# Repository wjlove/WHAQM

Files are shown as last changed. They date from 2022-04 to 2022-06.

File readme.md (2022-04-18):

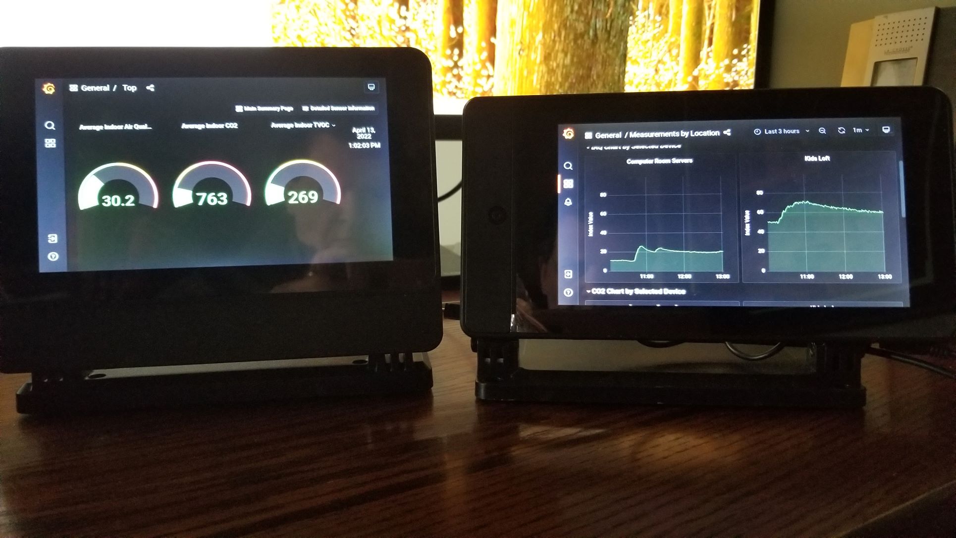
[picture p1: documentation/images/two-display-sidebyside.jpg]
The Whole Home Air Quality Monitoring Project
 

*An extension of the balenAIR project that allows for multiple sensor devices in various location within your home or any indoor location*

# Whole Home Air Quality Monitoring Project
**_Both this code and documentation are currently under construction)_**

## Reasoning

My office door is often closed and I was wondering if the quality of the air in my office was affecting my health. I wanted to measure/understand the levels of hazardous gasses and overall CO2 concentrations in my office during working hours as those are good indicators of the quality of the air in an enclosed space.   There are many products on the market that individuals can purchase that will monitor indoor air quality, however as a tinkerer I wanted to explore building one myself.  After some online research into DIY and open source projects I came across the excellent baleaAIR (https://github.com/balena-io-playground/balena-iaq) endeavor and thought this might be interesting to build.  I started collecting the necessary components and proceeded constructing one following the guidelines provided inline.  

During the process of testing my initial build device I noticed that the measurements reported were wildly different throughout the day and often those measurement readings were in the described danger or warning zones.  I thought I’d done everything correctly, and indeed the values were changing over time, so what was possible explanation?  As one of several tests, I moved my device to another room in my home and noted markedly different results, these measurements were stable and “safe” and changed very slowly over time.  With those results in hand, I visited several other rooms in my home and noticed each one produced results that were generally slightly different by location and fluctuated only mildly during the day.  

 It is from here I wondered if having a sensor device in each room, monitored by a central location might be useful and thus this project was born. (And of course, I also stopped closing my office door!)

## New Features

At its core, this project is simply an extension of the great work done on the balenAIR project and adds the following features:

- A balenAIR like device with a touchscreen display
- Ability to collect data from multiple balenaAIR and WHAQM devices
- Ability to display aggregated measurements from all devices
- Ability to use touchscren device to provide alerts - _currently broken due to prediction work, disabled_
- Ability to predict air quality conditions based on previous measurements - _not completed_

## Hardware Selection and Setup

The hardware items selected for use in this project are mostly defined by the balenAIR project and its original recommendations. There are a number of options when it comes to choosing these devices and cost, availability plus performance are some factors to consider when reviewing the parts below.

### Choosing your Pi

This project currently runs on a Raspberry Pi, so you'll need one of the following compatible devices:

- [Pi 3B](https://www.raspberrypi.com/products/raspberry-pi-3-model-b/)
- [Pi 3B+](https://www.raspberrypi.com/products/raspberry-pi-3-model-b-plus/)
- [Pi 4](https://www.raspberrypi.com/products/raspberry-pi-4-model-b/)

If you plan on having a significant number of sensor devices in multiple locations I would recommend that you consider using a Pi 4 as the main device. The air quality prediction software can be rather compute intensive over time and a Pi 4 also provides a "snappier" experience when using the touch screen.

### The Display and Case

There are several options for choosing a physical case that will house the Raspberry Pi, the touchscreen device and all the sensors. You can even consider making your own for a personal touch.  After some review and consideration I committed to the [SmartiPi Touch Pro - Small](https://smarticase.com/products/smartipi-touch-pro). It supports the original [Raspberry Pi Touch Display](https://www.raspberrypi.com/products/raspberry-pi-touch-display/) which I have selected as my prefered touchscreen device and has plenty of internal space to house all the necessary sensors.  Both are easily available for purchase, well supported and currently reasonably priced.  

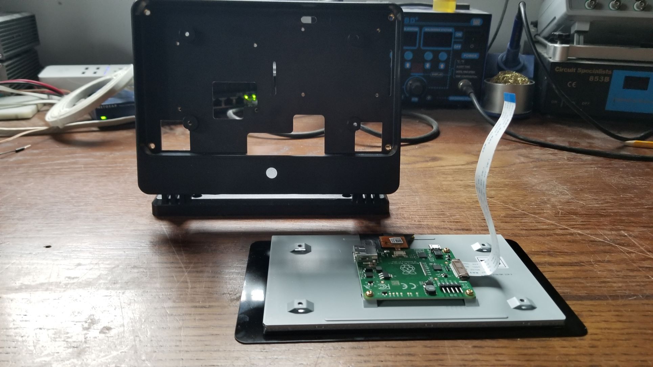
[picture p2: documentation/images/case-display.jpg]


### Sensors

The sensors used in this project evaluate the air surrounding the device and return data that is used to determine your air quality index or AQI. You can find more about how this number and how it is calculated at [AirNow](https://www.airnow.gov/aqi/aqi-basics/). Like balenAIR, WHAQM supports the three different sensors listed below. You can choose to have one, two, or all three present in your device, depending on your budget and air quality analysis needs.

| Sensor | Detects | Description |  Specifications (approx.) |
| --- | --- | --- | --- |
| [PMSA003I](https://www.adafruit.com/product/4632) | Smoke, dust, dirt, pollen particles | laser-scattering type  | 0.3-1.0,1.0-2.5, 2.5-10 Micrometer particles |
| [SCD-40](https://www.adafruit.com/product/5187) | Exhaled breath and burning fossil fuels |  CO2 photoacoustic sensor CO2 (plus temp and humidity)  | 400 - 2000 PPM |
| [SGP-30](https://www.adafruit.com/product/3709) | Gasses emitted by solid and liquid products  |  VOC (and eCO2) Hot-plate MOX sensor | eCO2 400-60,000 ppm, TVOC 0-60,000 ppb |

All of these sensors use the popular I2C protocol to communicate with the Pi and include [Qwiic](https://www.sparkfun.com/qwiic) connectors so you don't need to do any soldering to use these sensors.

### Sensor Carrier Board

Installing the sensors inside the SmartiPi case requires a seperate sensor carrier board.  Ideally and ultimately this will be a 3D printed part but considering the time involved in that process I simply fabricated one using a spare blank PCB.  You can read about that process [here](https://github.com/wjlove/WHAQM/blob/main/documentation/carrier-board.md) along with details about its dimensions and hole locations.
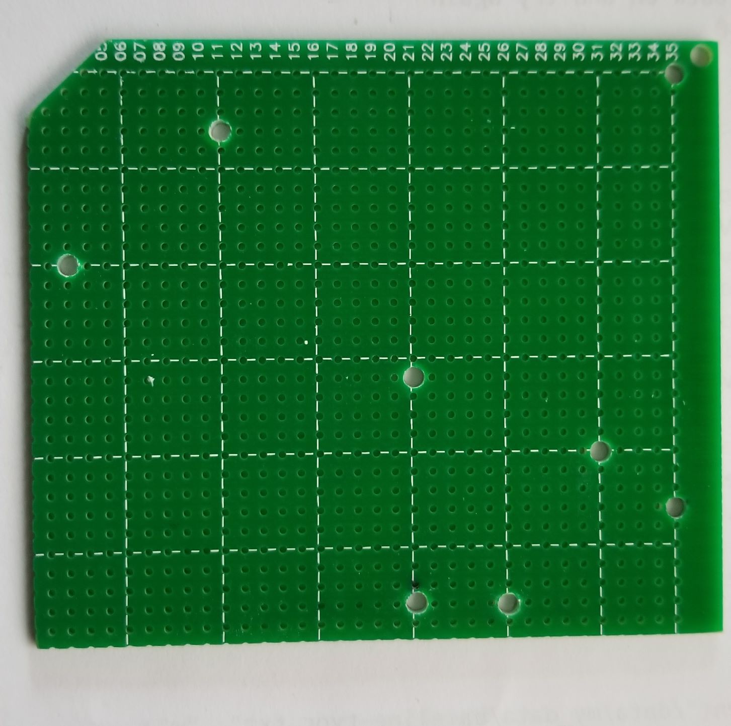
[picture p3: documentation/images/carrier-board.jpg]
 _Carrier board with holes_

As it currently stands this design is not ideal as a considerable amount of heat is generated internally by both the Raspberry Pi and the touchscreen display thus affecting the temperature measurements provided by the SCD-40 sensor unit by as much as 5 degrees.  Various insulating mitigations, as well as other air flow considerations, can be applied to the case and the sensor carrier board to reduce this effect. However my results to date have been varied and require further investigation.  The SmartiPi case does come with a fan which you can install and resolves this issue but the additional noise created by the fan was unacceptable to me.
### Miscellaneous Items

Additionally you will need some SparkFun qwiic cables to connect the sensors together [100mm QT to QT cable](https://www.adafruit.com/product/4210) and a qwiic to female header cable to connect the sensors to the Raspberry Pi you selected [Qwiic to female header cable](https://www.adafruit.com/product/4397).  Lastly you will need a way to affix the sensors to the carrier board, I used some M2 screws and bolts but you could also use plastic spacers or double sided tape but I wouldn’t recommend the latter.

### Putting it All Together

I will not go into significant detail about building the SmartiPi case and installing the Raspberry Pi touchscreen display as those details can be found on the [SmartiCase web site](https://smarticase.com/products/smartipi-touch-pro?variant=39297984790591).  Installing your Raspberry Pi of choice and the sensor carrier board on the rear of the case is done using the supplied screws.  You may want to attach the power adapter before installing the carrier board as it is significantly harder to do so with that installed. 

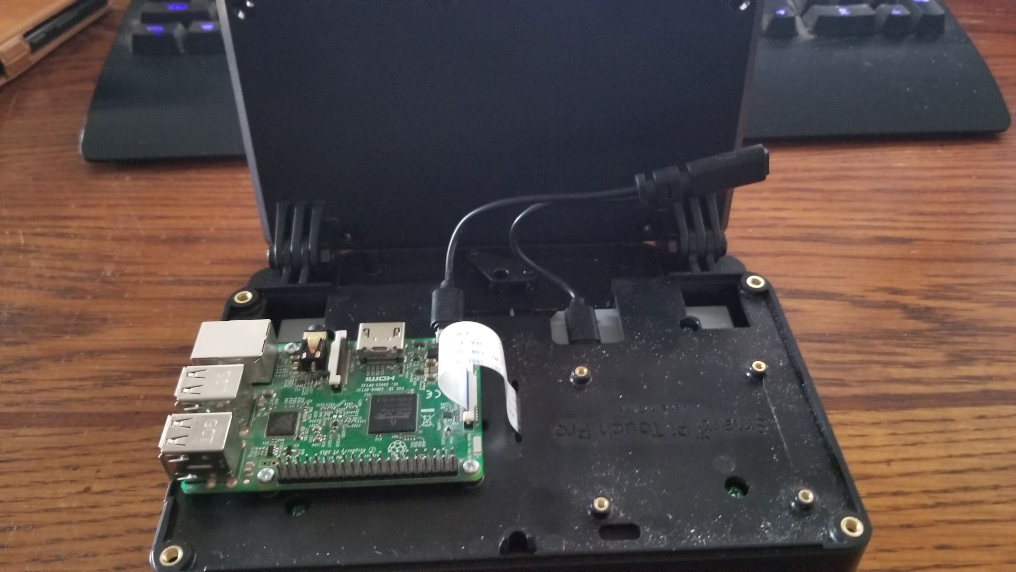
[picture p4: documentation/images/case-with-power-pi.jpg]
 *Install power connector first...*
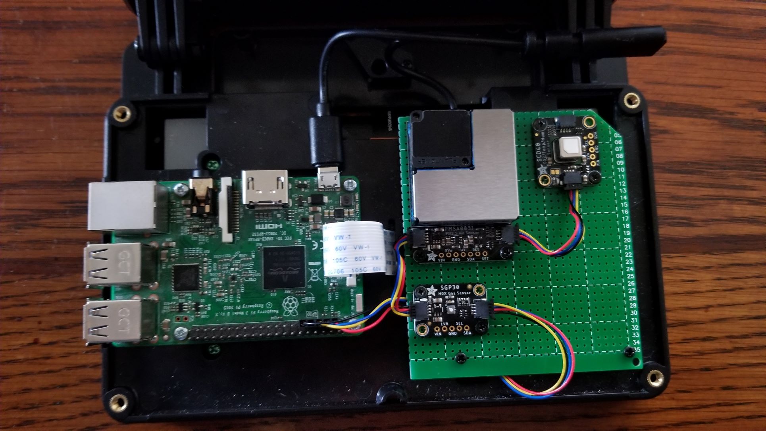
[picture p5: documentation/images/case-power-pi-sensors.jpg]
 *...then the sensors.*

Don’t put the back cover on just yet, we have to install the software and that requires access to the Raspberry Pi in the back.  

## Software Setup

This project assumes a fairly advanced level of knowledge about BalenaCloud and the steps to necessary to create a new fleet and new devices. If this is your first time deploying a project and you want to learn more about balena Cloud, I recommend familiarizing yourself by following the steps in this [Getting Started](https://www.balena.io/docs/learn/getting-started/raspberrypi4-64/nodejs/) tutorial.   While working with the tutorial keep in mind the Raspberry Pi device type you choose to use while building your WHAQM display as you will need to select the appropriate one while creating your fleet. After you have created a fleet with devices in your balenaCloud dashboard you can `balena push` this code to it the traditional way.

**_Or…._**

You can deploy this project in one click using the button below:

balena deploy button (https://dashboard.balena-cloud.com/deploy?repoUrl=https://github.com/wjlove/WHAQM)

This will automaticlly allow you to create (or use an existing) fleet, install the appropriate software and prepare everything for your first device deployment.  Pressing the button will walk you thru the necessary steps to get started. After providing the needed information balena Cloud will collect and build the appropriate software for your devices.  This will take some time, but you can follow the progress in the “Releases” window on the right:

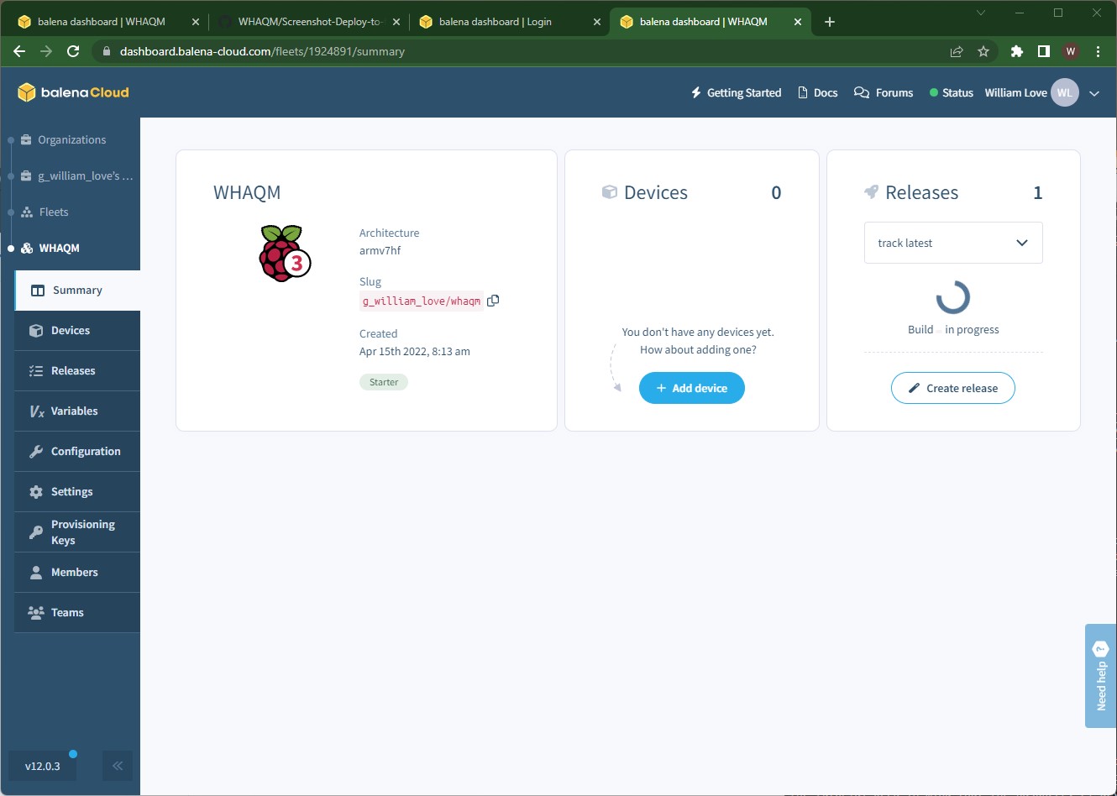
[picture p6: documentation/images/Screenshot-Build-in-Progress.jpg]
 _Build in progress_

When everything is complete you should see:

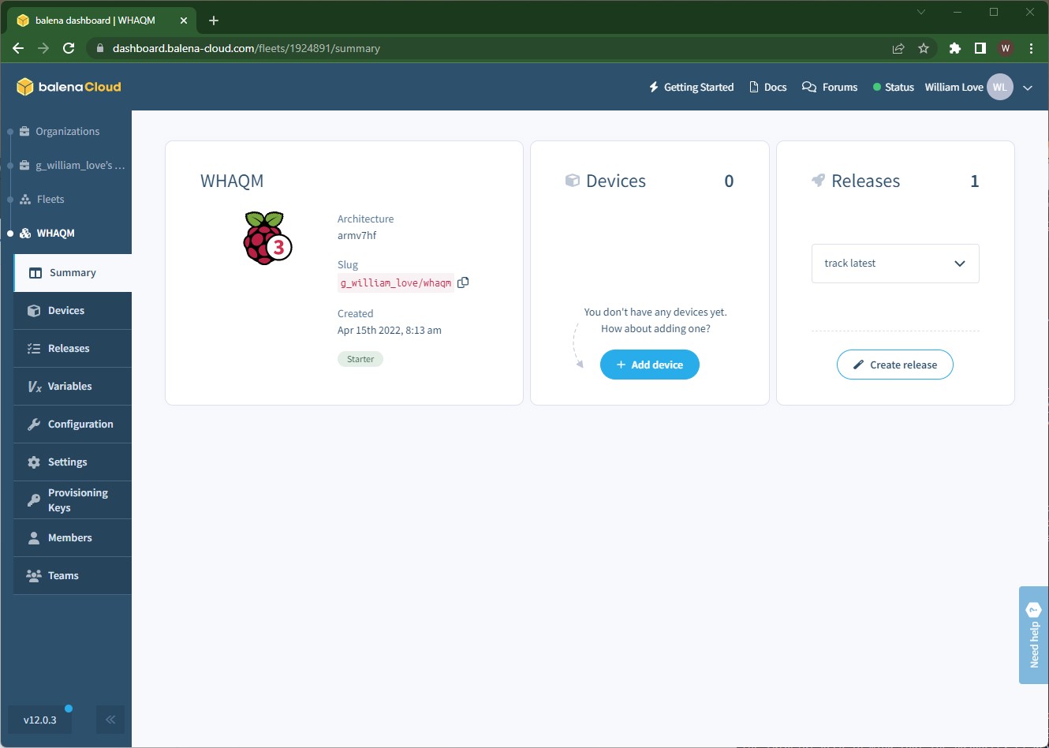
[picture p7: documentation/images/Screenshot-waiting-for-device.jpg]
 _Ready for your first device!_

Now you can add your first device by clicking on the “+ Add device” button.  While following the Instructions on the right be sure to remember the device type you used to build your display.  If you plan on using your device’s wireless networking ability be sure to select “Network Connection -> Wifi + Ethernet” and enter the appropriate network information.

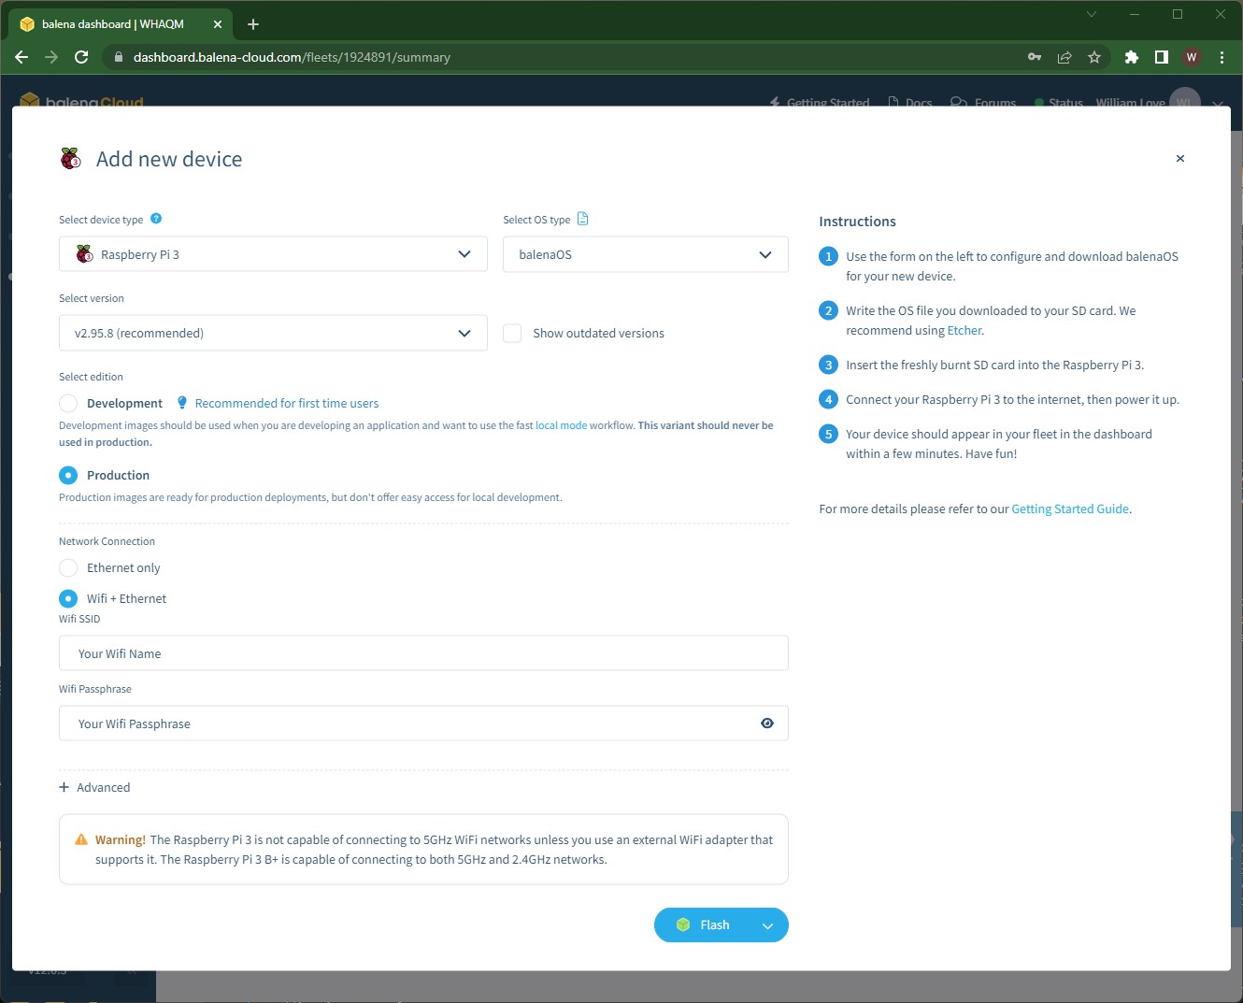
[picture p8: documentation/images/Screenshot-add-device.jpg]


((this section of my docuemnt needs work as the Instructions on the right are not completely clear on how to flash a device/SD card.  You need to either press the “Flash" button which automatically starts Etcher (if it is installed, if it is not installed then there are more steps), or select from the pull down nest to the "Flash" button to download the image file, ...and then flash it to the SD card with your software of choice.))

Once you have your freshly flashed SD card, install it in the Raspberry Pi:

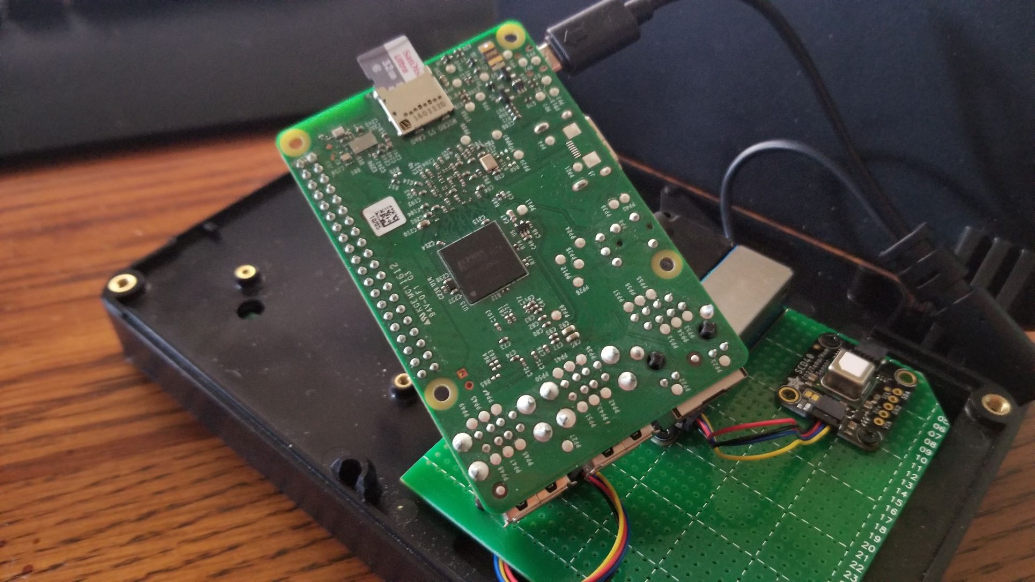
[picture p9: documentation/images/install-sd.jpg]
_SD card in back of the Raspberry Pi_

Power on the device and wait for it to boot up.  The first time the device powers up will take a significant amount of time as it needs to get an initial copy of the WHAQM software.  During this first step you should see the balena splash screen on your device:

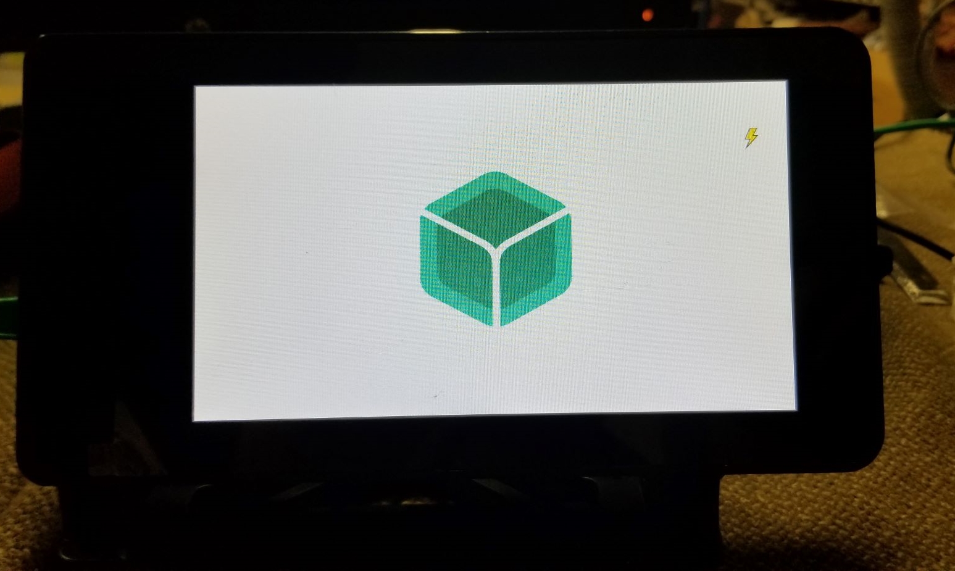
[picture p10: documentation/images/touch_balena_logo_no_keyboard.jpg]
 _Nice Logo…_

You can also verify that the software is being loaded on the device correctly by going to the balena Cloud dashboard and looking for a new device in the balena fleet you created.  In this example case, there is a device called “autumn-rock” and the “Status” is currently “Updating”:

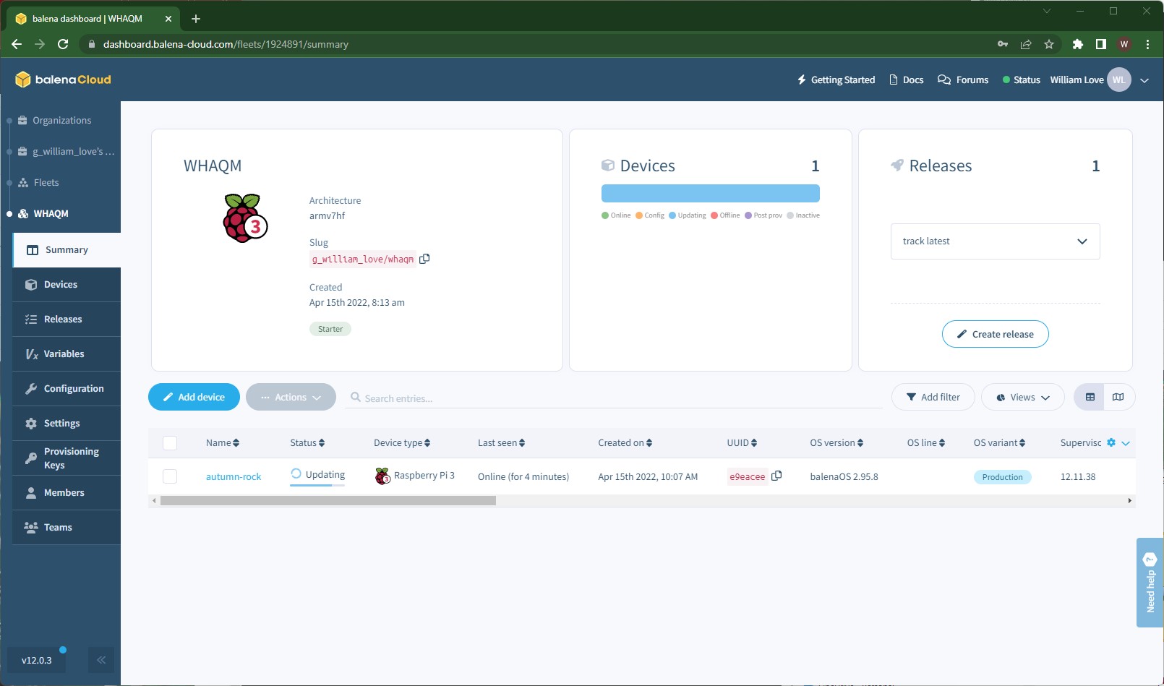
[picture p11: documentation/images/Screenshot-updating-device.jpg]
 

When the initial software has completed the loading process the “Status” will change to “Online” and you can click on the device name to get more detailed information about the device and the software that is running:

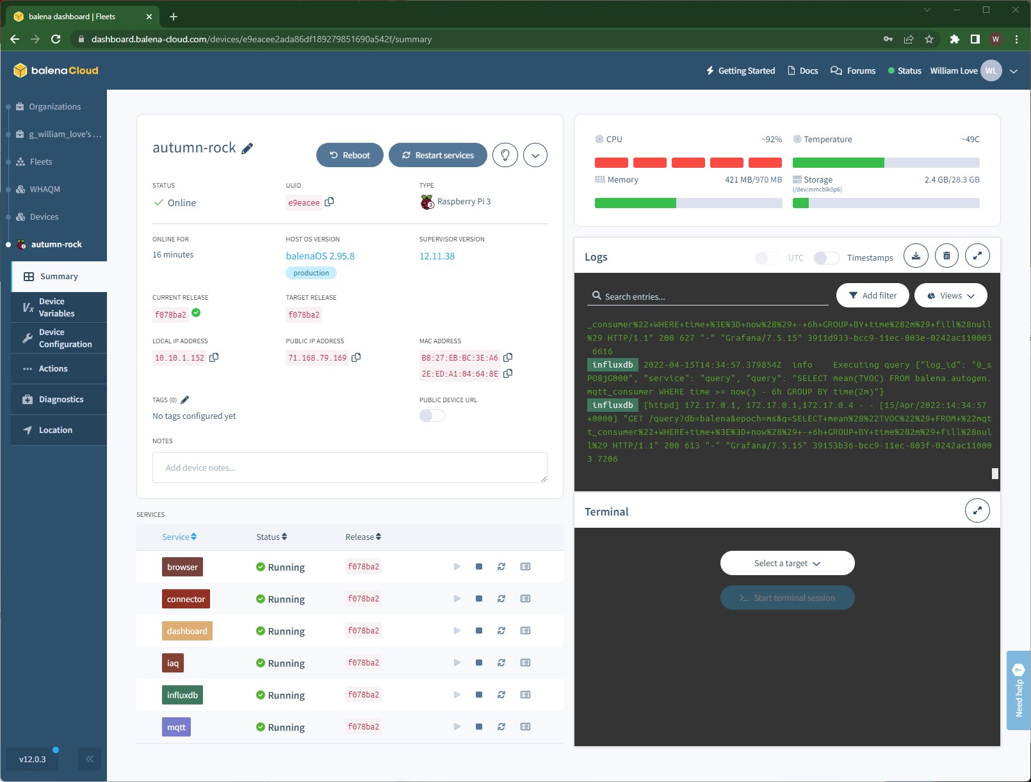
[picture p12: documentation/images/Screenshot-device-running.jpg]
_…you should see something like this…_

…and you should see the General/Top Screen on your WHAQM device:

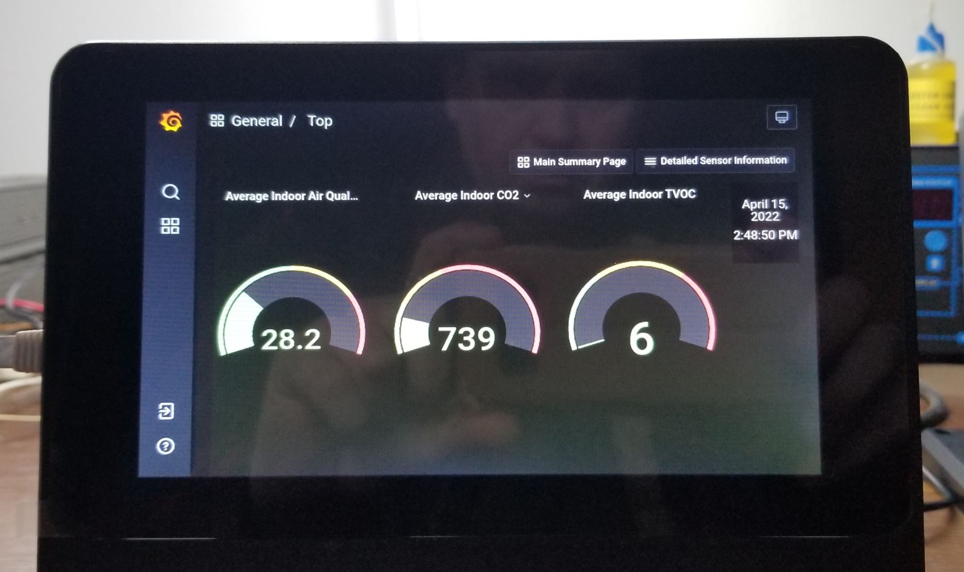
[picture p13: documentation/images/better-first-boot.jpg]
 _…nothing more to do here!_

### Using the WHAQM software

Design Goal Intro-  Using as many perdefined balena blocks as possible with as little modificationa as possible to build a new project.  Only real software modifications here are found in IAQ.py and Dashboard, all the hard work is handled by generic balena blocks.

***_outline_***

Intro-  

- brief overview of menus
  - top
    - main summary page
    - detailed sensor information
    - location measurement details
    - measurements by location

- review some of the buttons
    - time period
    - manual refresh
    - automatic refresh selection
    - view mode - add warning about touchscreen (can not disable yet)

- direct access via web browser
- making changes to Grafana dashboards

### Adding more devices....

***_outline_***

- currently supported devices
    - balenaAIR
    - WHAQM

- need WHAQM_SENSOR_NAME
- need modify mosquitto.conf file in MQTT container with WHAQM_COLLECTOR_URL
- for WHAQM devices, point browser block to WHAQM_COLLECTOR_URL

### Troubleshooting

- Software Tools
    - MQTT Explorer
    - InfluxBD Studio
    - Grafana Website

- HArdware Tools
    - ???

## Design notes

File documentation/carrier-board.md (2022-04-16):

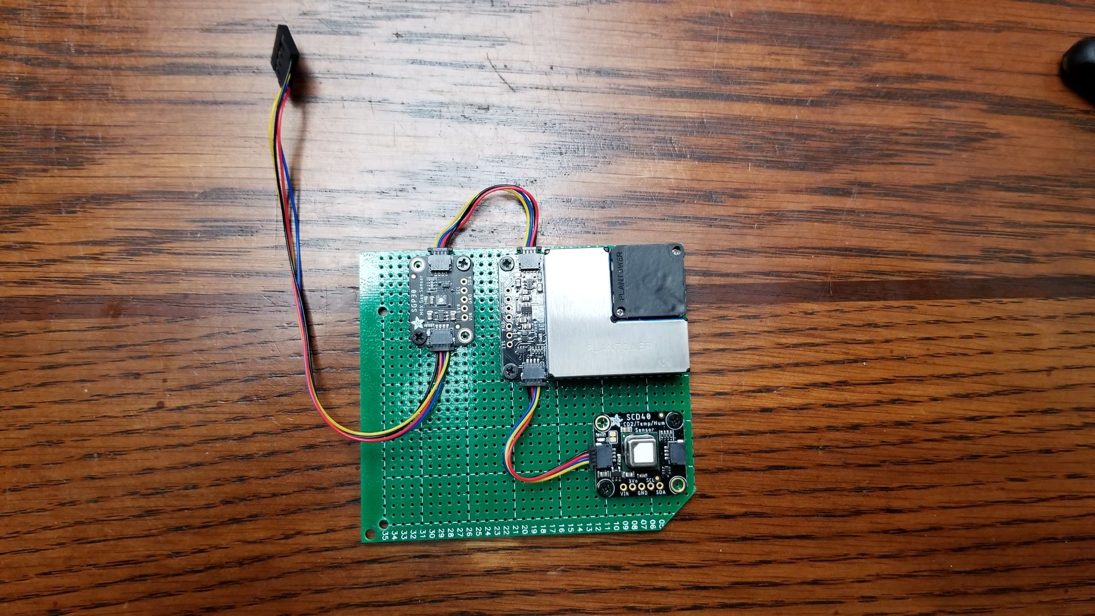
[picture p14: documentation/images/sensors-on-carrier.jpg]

_Solution to install sensors inside TouchScreen case for WHAQM project_

## WHAQM Sensor Carrier Board

Ultimately the sensor carrier board will be 3D printed but for now I just wanted to get something in place that would keep the build process moving along.  I happened to have some extra PCB prototyping boards in my parts supply so using them was a simple short term solution.  The process would include identifying a usable board and then drilling some holes to affix the sensors to the board with some M2 sized screws.  Using screws for my initial designs facilitated the ability to move various sensors as I explored placement options.  This would be very instrumental later as thermal issues became more problematic than expected. 

My initial selection of possible options produced these three boards:

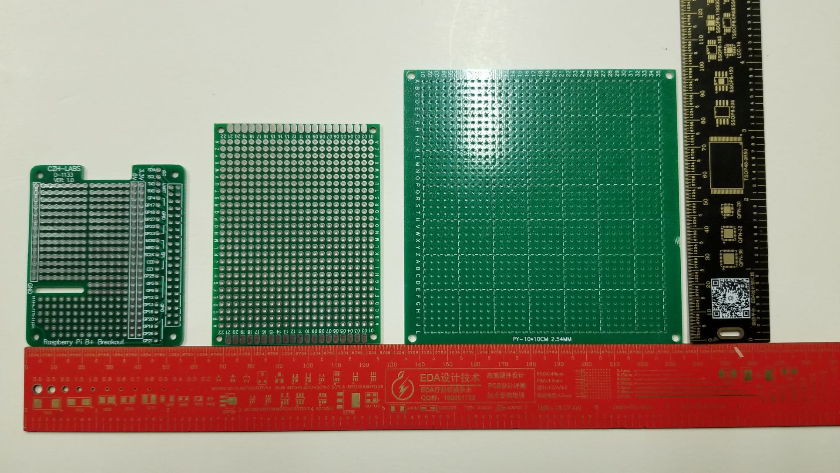
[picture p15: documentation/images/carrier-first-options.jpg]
_Some PCB options_

The first board on the left is an original Raspberry Pi Hat prototyping board and while it already has the case mounting holes pre-drilled it was too small to hold all three sensors. The middle board had enough space but needed holes drilled for mounting in the case.  The last board on the right is too large for the case and will need case mounting holes drilled as well.  

Originally I selected the middle board and proceeded to drill holes to accommodate the three sensor devices:  
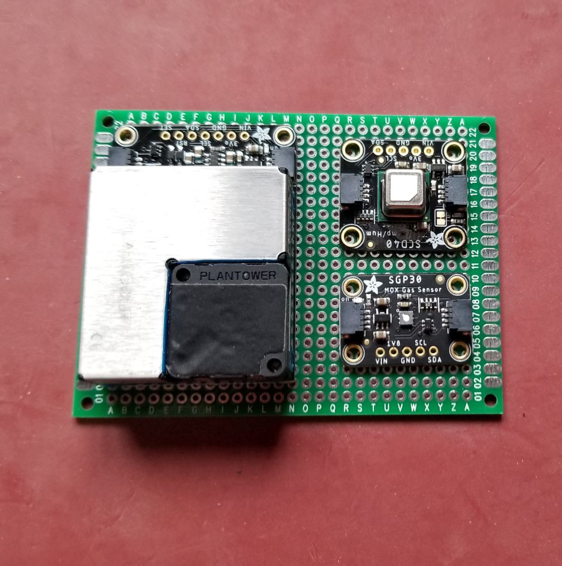
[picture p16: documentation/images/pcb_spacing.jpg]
_Sensor layout_

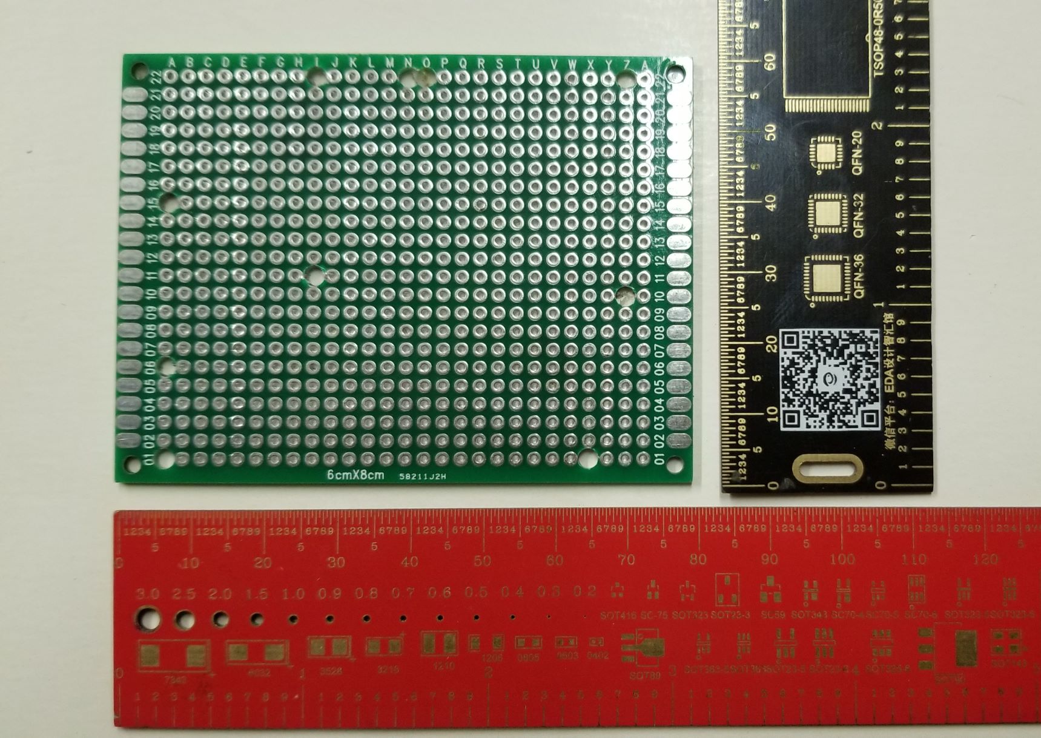
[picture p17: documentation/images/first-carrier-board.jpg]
_Holes drilled_

This board worked well for my initial builds but it soon became apparent that  due to thermal considerations there would be a requirement  for a more accommodating sensor placement.  As a result it was necessary to use the larger blank PCB and modify it to fit in the SmartiPi case as well as drill new holes.

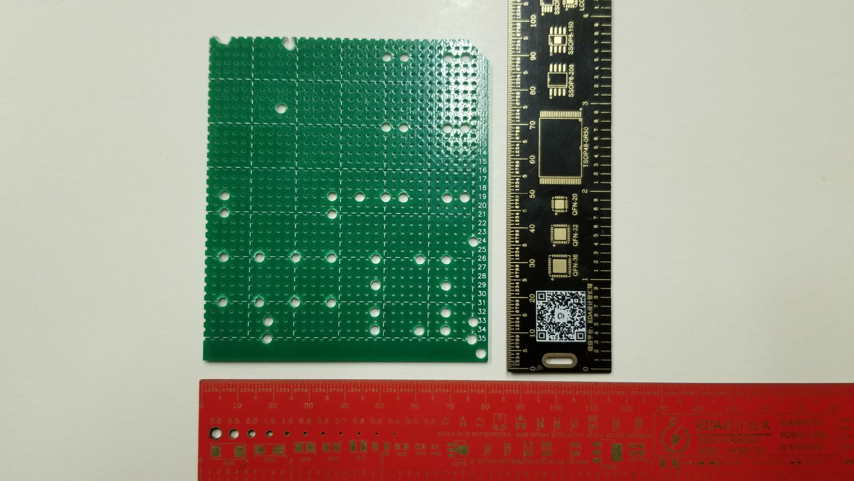
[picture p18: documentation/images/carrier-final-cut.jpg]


The process of sizing and cutting the board was rather simple using the SmartiPi case as a quide and a small saw to do the cuts. 

 Here are a few images of that process:

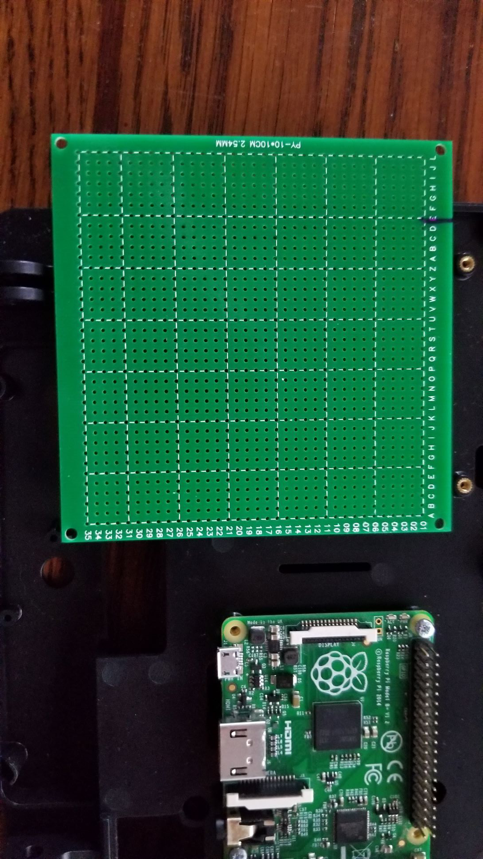
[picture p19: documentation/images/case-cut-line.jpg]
_Marking a cut line_

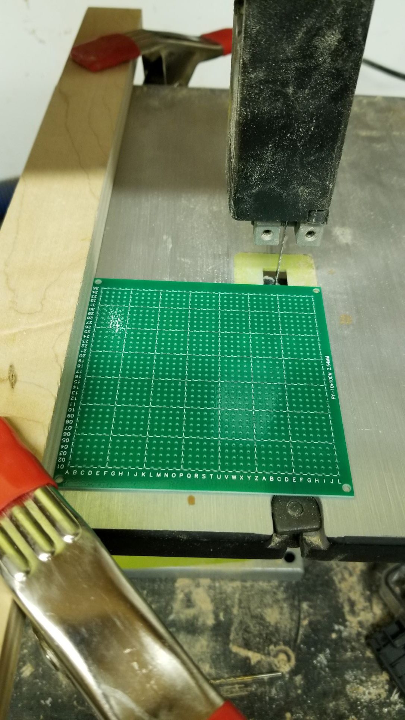
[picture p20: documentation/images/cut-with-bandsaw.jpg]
_Cutting with bandsaw - watch those fingers!_

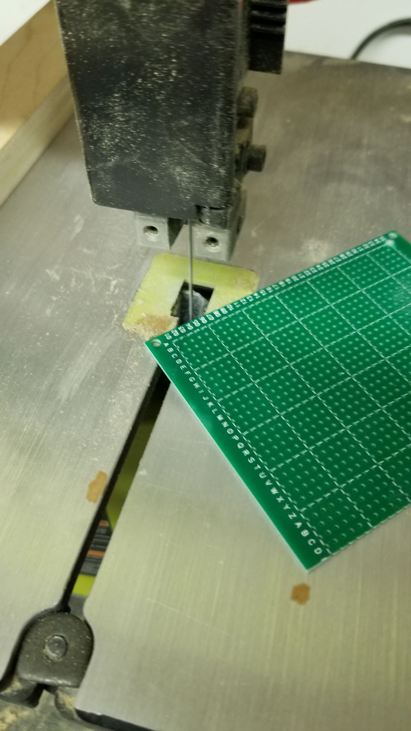
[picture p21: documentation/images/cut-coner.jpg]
_Small corner cut for case screws_

After the PCB was modified to size I experimented with sensor placement over a period of several weeks.  Each new configuration required a new set of holes and ultimately resulted in a board that looked like this:

_Final board with holes for various sensor configurations_

My current sensor placement on the carrier board is shown in the image at the beginning of this document and for the readers reference the final hole placement is shown below:

_Current hole requirements_

_Finished!_

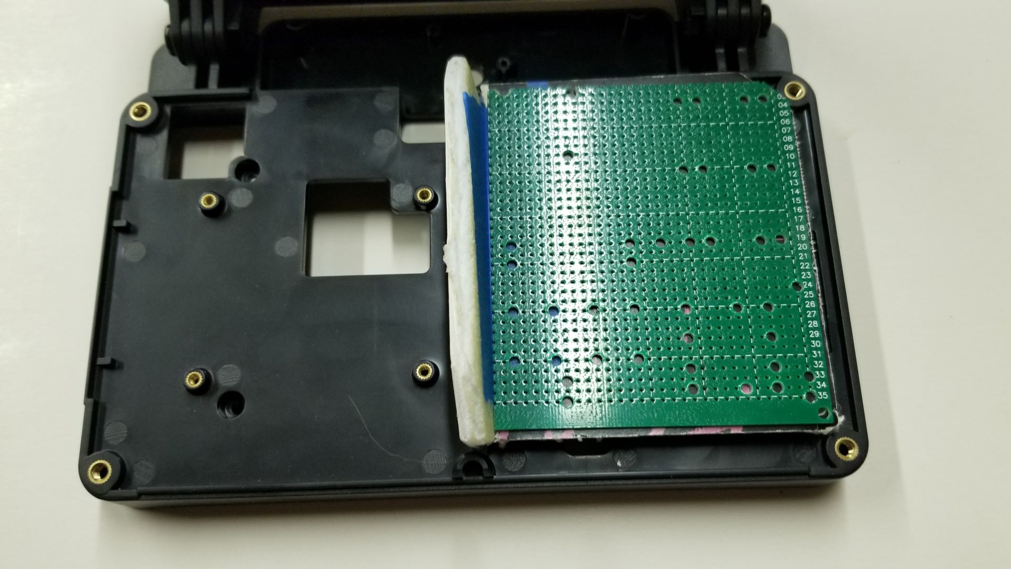
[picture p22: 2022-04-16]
documentation/images/pcb-with-posterboard.jpg

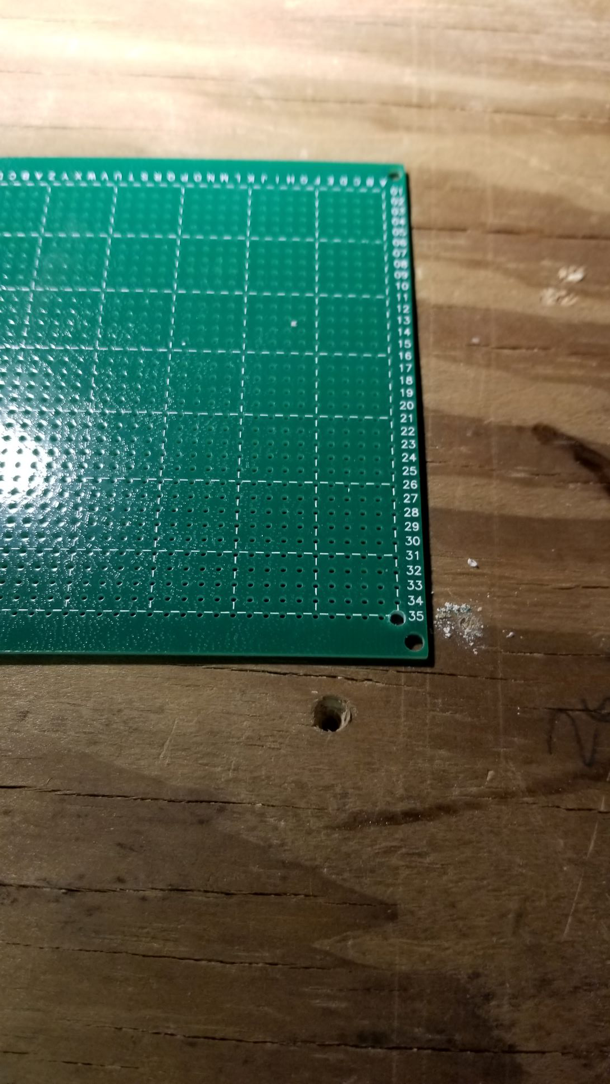
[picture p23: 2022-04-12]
documentation/images/first-hole.jpg

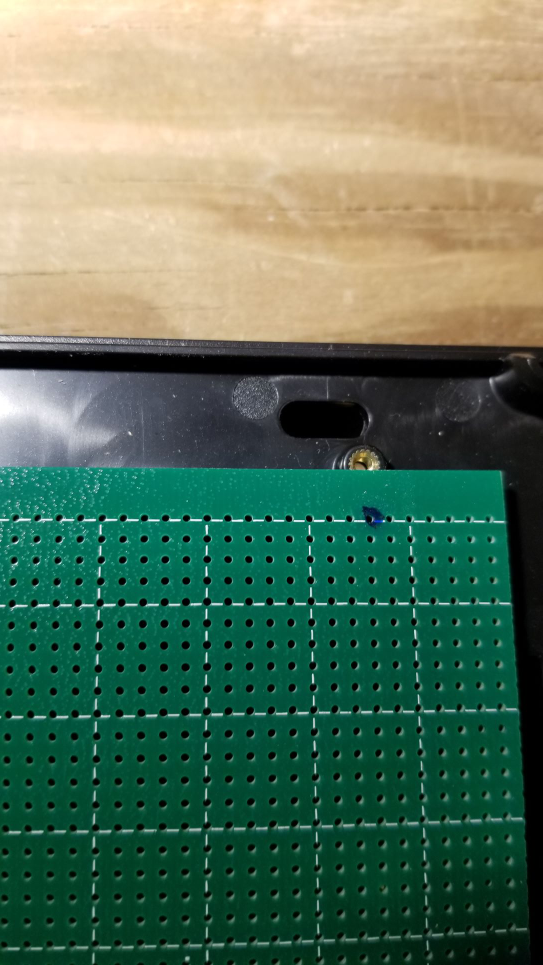
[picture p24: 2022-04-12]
documentation/images/second-hole.jpg

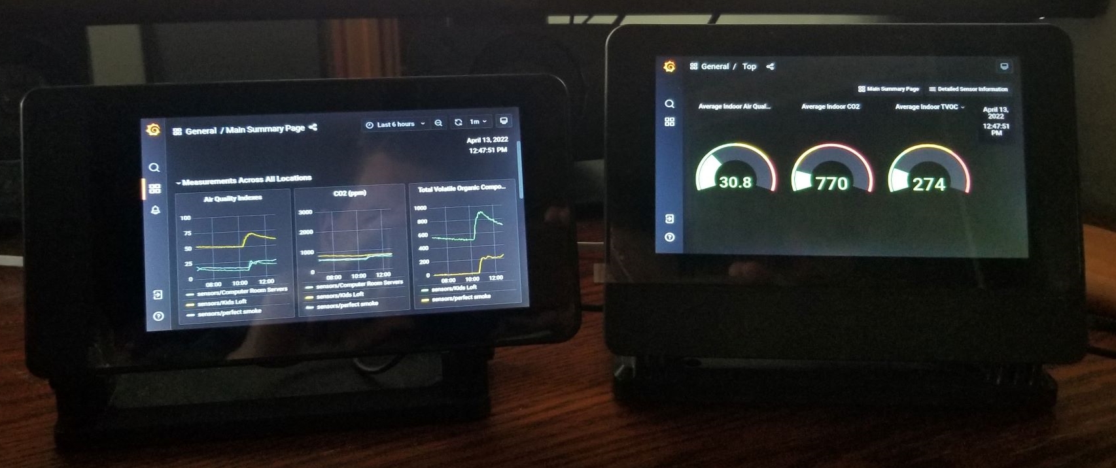
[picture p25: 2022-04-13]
documentation/images/two-display-v2.jpg

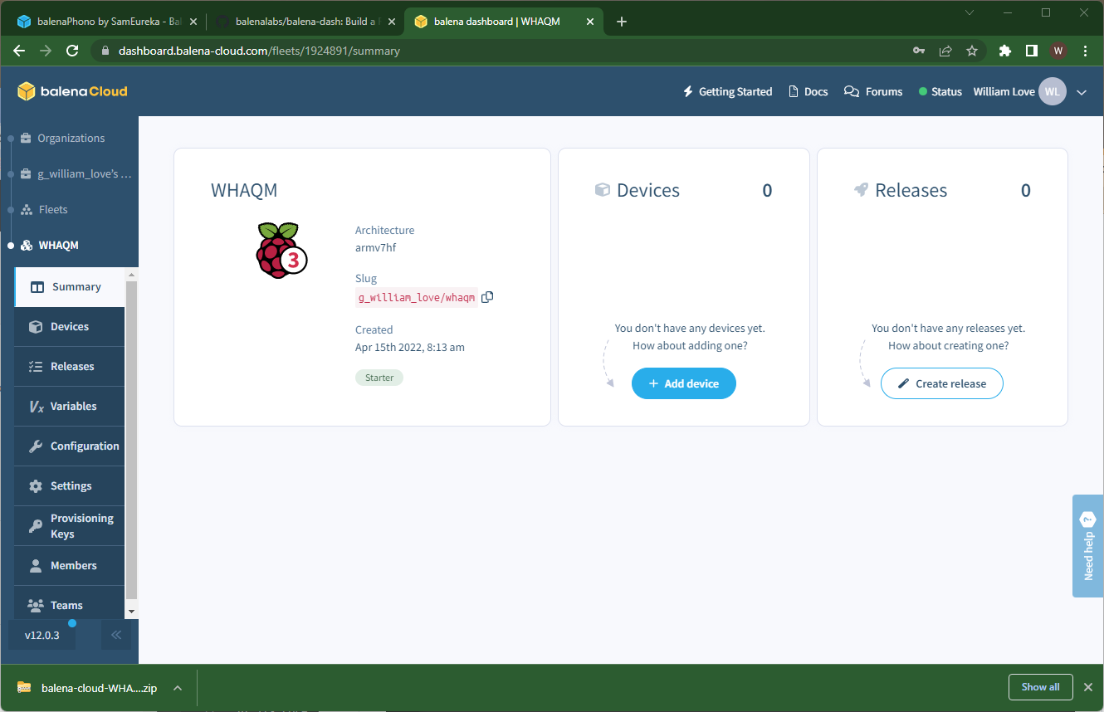
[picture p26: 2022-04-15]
documentation/images/Screenshot-Fleet-no-Devices.png

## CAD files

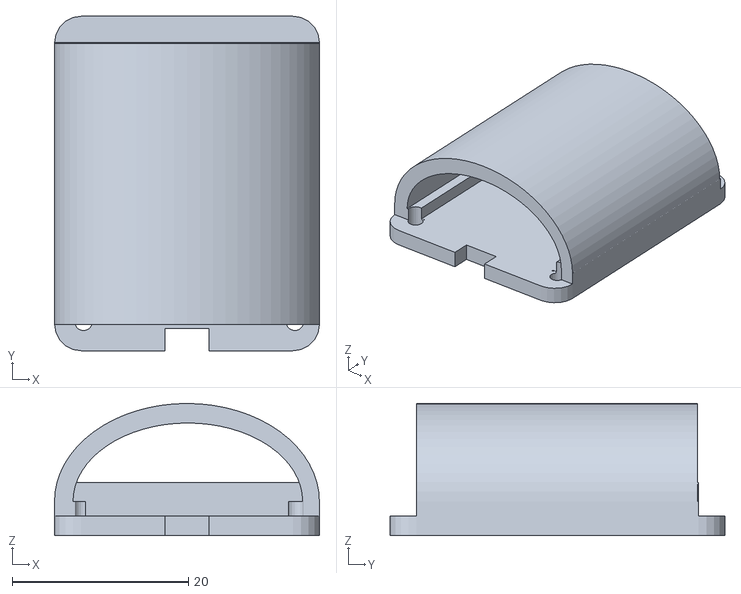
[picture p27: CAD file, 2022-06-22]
stl Files/Sensor Cover v10.stl
30.1 x 38.0 x 15.0

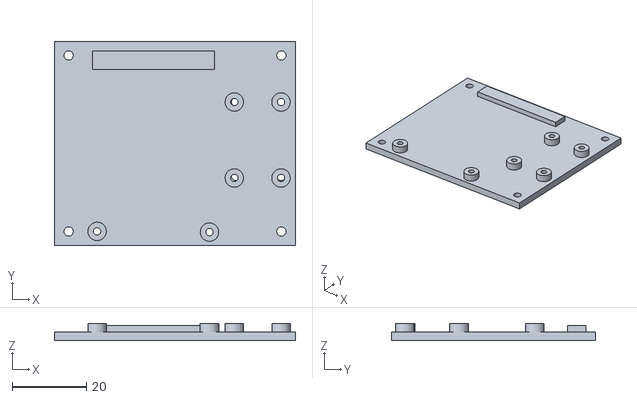
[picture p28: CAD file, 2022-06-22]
stl Files/Sensor Plate v4.stl
65.0 x 55.0 x 4.60

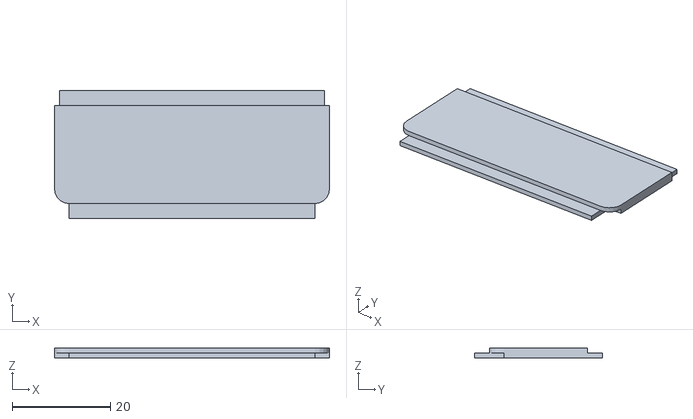
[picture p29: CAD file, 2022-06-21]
stl Files/Port Cover v1.stl
56.0 x 26.0 x 2.00

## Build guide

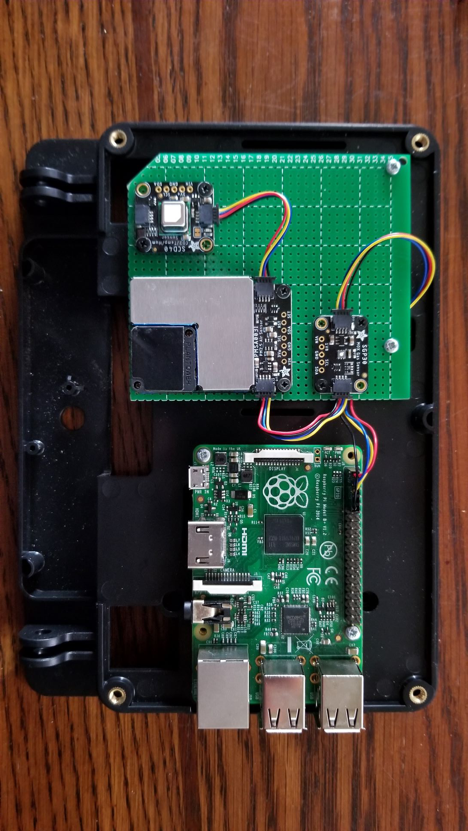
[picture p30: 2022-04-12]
documentation/images/installed-sensors.jpg

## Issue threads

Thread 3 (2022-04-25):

End nodes fail if Collector device changes IP address

wjlove, 2022-04-25:
It is possible that the ip address of the main collector device will change.  When this happens other devices no longer know which mqtt broker to send data to as the ip address of the collector is statically set in the the mqtt config file.

wjlove, 2022-04-25:
Suggest using DNS-SD with multicast.

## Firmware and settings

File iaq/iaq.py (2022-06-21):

# SPDX-FileCopyrightText: 2021 ladyada for Adafruit Industries SPDX-License-Identifier: MIT
# pylint: disable=unused-import
import time
import board
import busio
import json
from adafruit_pm25.i2c import PM25_I2C
import qwiic_led_stick
import paho.mqtt.client as mqtt
import os
import sys
import adafruit_sgp30
import binascii
import display
import logging


PM25_MAX = 250
PM10_MAX = 430
CO2_MAX = 5000
PM25_RED = 55
PM10_RED = 150
CO2_RED = 2000
PM25_YELLOW = 35
PM10_YELLOW = 54
CO2_YELLOW = 1000
CO2_MIN = 400
VOC_MIN = 0
VOC_MAX = 10000
VOC_YELLOW = 500
VOC_RED = 1000
BASELINE_LIMIT = 720  # 720 minutes = 12 hours
pm_sensor = 1
scd_sensor = 1
voc_sensor = 1
bar_graph = 0
matrix_display = 0
scd_timeout = 0

# Sleep time for each cycle. Normally 60 secs.
# Some other operations are derived from this:
cycle_time = 60
voc_baseline_count = 0
voc_baseline_eco2 = 0 # was 0x8973
voc_baseline_tvoc = 0 # was 0x8AAE
voc_baseline_limit = 60


green_limit = 50
yellow_limit = 75

pm10_idx = 0
pm25_idx = 0
co2_idx = 0
voc_idx = 0

# Get ENV vars:

try:
    alert_mode = int(os.getenv('ALERT_MODE', '0'))
except Exception as e:
    print("Invalid value for ALERT_MODE. Using default 0.")
    alert_mode = 0

try:
    alert_level = int(os.getenv('ALERT_LEVEL', '50'))
except Exception as e:
    print("Invalid value for ALERT_LEVEL. Using default 50.")
    alert_level = 50
 
try:
    zero_bar = int(os.getenv('ZERO_BAR', '1'))
except Exception as e:
    print("Invalid value for ZERO_BAR. Using default 1.")
    zero_bar = 1

try:
    del_baseline = int(os.getenv('DELETE_BASELINE', '0'))
except Exception as e:
    print("Invalid value for DELETE_BASELINE. Using default 0.")
    del_baseline = 0

try:
    bar_mode = int(os.getenv('BAR_MODE', '1'))
except Exception as e:
    print("Invalid value for BAR_MODE. Using default 1.")
    bar_mode = 1

try:
    log_level = os.getenv('LOG_LEVEL', 'WARNING')
except Exception as e:
    print("Invalid value for LOG_LEVEL. Using default 'WARNING'.")
    log_level = 'WARNING'
#
# Setting a IAQ node name from for use with the WHAQM project.  If no name is assigned assume it is not yet part of the WAHQM project.
pretty_host_name = os.getenv('WHAQM_SENSOR_NAME', 'No Room Assigned')
pretty_host_name = pretty_host_name.replace("/", "_")
pretty_host_name = pretty_host_name.replace("-", " ")
pretty_host_name = pretty_host_name.replace("$", "_")
pretty_host_name = pretty_host_name.replace("+", "_")
pretty_host_name = pretty_host_name.replace("#", "_")

# Set up logger
logger = logging.getLogger('iaq_logger')
logger.setLevel(logging.DEBUG)  # Passes all messages to handlers

# Create handlers
c_handler = logging.StreamHandler(stream=sys.stdout)

if log_level == 'DEBUG':
    c_handler.setLevel(logging.DEBUG)
elif log_level == 'INFO':
    c_handler.setLevel(logging.INFO)
elif log_level == 'WARNING':
    c_handler.setLevel(logging.WARNING)
elif log_level == 'ERROR':
    c_handler.setLevel(logging.ERROR)
elif log_level == 'CRITICAL':
    c_handler.setLevel(logging.CRITICAL)
else:
    c_handler.setLevel(logging.WARNING)

print("log_level: {}".format(log_level))    
# Add handlers to the logger
logger.addHandler(c_handler)

logger.critical("You will see CRITICAL log entries.")
logger.debug("You will see DEBUG log entries.")
logger.error("You will see ERROR log entries.")
logger.warning('You will see WARNING log entries.')
logger.info("You will see INFO log entries.")

reset_pin = None
# If you have a GPIO, its not a bad idea to connect it to the RESET pin
# reset_pin = DigitalInOut(board.G0)
# reset_pin.direction = Direction.OUTPUT
# reset_pin.value = False


# For use with a computer running Windows:
# import serial
# uart = serial.Serial("COM30", baudrate=9600, timeout=1)

# For use with microcontroller board:
# (Connect the sensor TX pin to the board/computer RX pin)
# uart = busio.UART(board.TX, board.RX, baudrate=9600)

# For use with Raspberry Pi/Linux:
# import serial
# uart = serial.Serial("/dev/ttyS0", baudrate=9600, timeout=0.25)

# For use with USB-to-serial cable:
# import serial
# uart = serial.Serial("/dev/ttyUSB0", baudrate=9600, timeout=0.25)

# Connect to a PM2.5 sensor over UART
# from adafruit_pm25.uart import PM25_UART
# pm25 = PM25_UART(uart, reset_pin)

# Create library object, use 'slow' 100KHz frequency!
i2c = busio.I2C(board.SCL, board.SDA, frequency=100000)
# Connect to a PM2.5 sensor over I2C
try:
    pm25 = PM25_I2C(i2c, reset_pin)
except Exception as e:
    logger.info("No PM2.5 sensor found...")
    pm_sensor = 0
else:
    logger.info("Found PM2.5 sensor, reading data...")
    
# SPDX-FileCopyrightText: 2020 by Bryan Siepert, written for Adafruit Industries
#
# SPDX-License-Identifier: Unlicense
import adafruit_scd4x

try:
    scd4x = adafruit_scd4x.SCD4X(i2c)
except Exception as e:
    logger.info("No SCD sensor found...")
    scd_sensor = 0
else:
    serial_num = [hex(i) for i in scd4x.serial_number]
    logger.info("Found SCD sensor: Serial number: {}".format(serial_num))

import board
from adafruit_ht16k33.matrix import Matrix8x8x2

try:
    matrix2 = Matrix8x8x2(i2c, address=0x70)
    matrix1 = Matrix8x8x2(i2c, address=0x71)
except Exception as e:
#WJL    logger.info("No LED matrix found, using LED bar graph...")
    logger.info("No LED matrix found...")
#WJL    bar_graph = 1
else:
    matrix_display = 1

# Delete baseline file(s) if device variable set
if del_baseline != 0:
    logger.warning("Baseline file will be deleted!")
    logger.warning("Change DELETE_BASELINE device variable to 0 after delete!")
    if os.path.exists("/data/my_data/baseline-eco2.txt"):
        os.remove("/data/my_data/baseline-eco2.txt")
    else:
        logger.info("The file /data/my_data/baseline-eco2.txt does not exist.")
    if os.path.exists("/data/my_data/baseline-tvoc.txt"):
        os.remove("/data/my_data/baseline-tvoc.txt")
    else:
        logger.info("The file /data/my_data/baseline-tvoc.txt does not exist.") 
    
# Create library object on our I2C port
try:
    sgp30 = adafruit_sgp30.Adafruit_SGP30(i2c)
except Exception as e:
    logger.info("No SGP VOC sensor found...")
    voc_sensor = 0
else:
    serial_num = [hex(i) for i in sgp30.serial]
    logger.info("Found VOC sensor: SGP30 serial #{}".format(serial_num))
    try:
        f = open("/data/my_data/baseline-eco2.txt", "r")
    except Exception as e:
        logger.info("No eCO2 baseline file found. Calculating new 12hr baseline...")
        voc_baseline_limit = BASELINE_LIMIT
    else:
        try:
            voc_baseline_eco2 = int(f.read())
        except:
            print("Invalid/no data found in eCO2 baseline file. Deleting file and calculating new baseline...")
            f.close()
            voc_baseline_limit = BASELINE_LIMIT
            os.remove("/data/my_data/baseline-eco2.txt")
        else:
            f.close()
      
    try:
        f = open("/data/my_data/baseline-tvoc.txt", "r")
    except Exception as e:
        logger.info("No TVOC baseline file found. Calculating new 12hr baseline...")
        voc_baseline_limit = BASELINE_LIMIT
    else:
        try:
            voc_baseline_tvoc = int(f.read())
        except:
            print("Invalid/no data found in TVOC baseline file. Deleting file and calculating new baseline...")
            f.close()
            voc_baseline_limit = BASELINE_LIMIT
            os.remove("/data/my_data/baseline-tvoc.txt")
        else:
            f.close()
    sgp30.iaq_init()
    if (voc_baseline_eco2 != 0) and (voc_baseline_tvoc != 0):
        logger.info("Setting VOC baseline from file: eCO2: {0}; tvoc: {1}".format(voc_baseline_eco2, voc_baseline_tvoc))
        sgp30.set_iaq_baseline(voc_baseline_eco2, voc_baseline_tvoc)
    logger.info("Initial eCO2 = %d ppm \t TVOC = %d ppb" % (sgp30.eCO2, sgp30.TVOC))

# For LED bar graph:
#WJL if bar_graph == 1:
#WJL    my_stick = qwiic_led_stick.QwiicLEDStick()
#WJL    time.sleep(0.75)
#WJL    my_stick.LED_off()


my_stick = qwiic_led_stick.QwiicLEDStick()
if my_stick.begin() == True:
    bar_graph = 1
    my_stick = qwiic_led_stick.QwiicLEDStick()
    time.sleep(0.75)
    my_stick.LED_off()
else:
    print("No LED stick found, not using LED stick...")

def scd_sense():
    #
    # Take a reading from the CO2 sensor, return dict
    #
    global scd_timeout
    scd_dict = {}
    count = 0
    while not scd4x.data_ready:
        count = count + 1
        print("Waiting for scd4x  measurement ({0})....".format(count))
        time.sleep(1)
        if count > 15:
            logger.warning("scd4x reading timed out! No CO2 data available!")
            scd_timeout = 1
            return scd_dict
            

    logger.info("CO2: %d ppm" % scd4x.CO2)
    logger.info("Temperature: %0.1f *C" % scd4x.temperature)
    logger.info("Humidity: %0.1f %%" % scd4x.relative_humidity)
    #print()

    scd_dict["co2"] = scd4x.CO2
    scd_dict["temperature"] = scd4x.temperature
    scd_dict["humidity"] = scd4x.relative_humidity
    
    return scd_dict

def pm_sense():
    #
    # Take a reading from the particulate sensor, return dict
    #
    try:
        aqdata = pm25.read()
    except RuntimeError:
        logger.warning("Unable to read from PM sensor, retrying...")
        time.sleep(1)
        try:
            aqdata = pm25.read()
        except RuntimeError:
            logger.warning("Unable to read from PM sensor, retrying (2)...")
            time.sleep(2)
            try:
                aqdata = pm25.read()
            except RuntimeError:
                logger.warning("Unable to read from PM sensor (3), skipping...")
                return {}

    logger.info("Concentration Units (standard)")
    logger.info("---------------------------------------")
    logger.info("PM 1.0: {0} PM2.5: {1} PM10: {2}".format(aqdata["pm10 standard"], aqdata["pm25 standard"], aqdata["pm100 standard"]))
    logger.info("Concentration Units (environmental)")
    logger.info("---------------------------------------")
    logger.info("PM 1.0: {0} PM2.5: {1} PM10: {2}".format(aqdata["pm10 env"], aqdata["pm25 env"], aqdata["pm100 env"]))
    logger.debug("---------------------------------------")
    logger.debug("Particles > 0.3um / 0.1L air:{}".format(aqdata["particles 03um"]))
    logger.debug("Particles > 0.5um / 0.1L air:{}".format(aqdata["particles 05um"]))
    logger.debug("Particles > 1.0um / 0.1L air:{}".format(aqdata["particles 10um"]))
    logger.debug("Particles > 2.5um / 0.1L air:{}".format(aqdata["particles 25um"]))
    logger.debug("Particles > 5.0um / 0.1L air:{}".format(aqdata["particles 50um"]))
    logger.debug("Particles > 10 um / 0.1L air:{}".format(aqdata["particles 100um"]))
    logger.debug("---------------------------------------")

    return aqdata

def voc_sense():
    #
    # Take a reading from the VOC SGP30 sensor, return dict
    #
    voc_dict = {}
    logger.info("VOC sensor reading: eCO2 = {0} ppm \t TVOC = {1} ppb".format(sgp30.eCO2, sgp30.TVOC))
    voc_dict["eCO2"] = sgp30.eCO2
    voc_dict["TVOC"] = sgp30.TVOC

    return voc_dict

def pm25_index(pm25):
    #
    # Calculates our 0-99 AQ index for pm25
    #
    scaled_pm25 = 0

    if pm25 < PM25_YELLOW:
        scaler = make_interpolater(0, PM25_YELLOW, 0, 50)
        scaled_pm25 = scaler(pm25)
    elif pm25 < PM25_RED:
        scaler = make_interpolater(PM25_YELLOW, PM25_RED, 50, 75)
        scaled_pm25 = scaler(pm25)
    else:
        scaler = make_interpolater(PM25_RED, PM25_MAX, 75, 99)
        scaled_pm25 = scaler(pm25)
      
    if scaled_pm25 > 99:
        scaled_pm25 = 99
        
    return scaled_pm25

def pm10_index(pm10):
    #
    # Calculates our 0-99 AQ index for pm10
    #
    scaled_pm10 = 0

    if pm10 < PM10_YELLOW:
        scaler = make_interpolater(0, PM10_YELLOW, 0, 50)
        scaled_pm10 = scaler(pm10)
    elif pm10 < PM10_RED:
        scaler = make_interpolater(PM10_YELLOW, PM10_RED, 50, 75)
        scaled_pm10 = scaler(pm10)
    else:
        scaler = make_interpolater(PM10_RED, PM10_MAX, 75, 99)
        scaled_pm10 = scaler(pm10)

    if scaled_pm10 > 99:
        scaled_pm10 = 99
        
    return scaled_pm10

def co2_index(co2):
    #
    # Calculates our 0-99 AQ index for co2
    #
    scaled_co2 = 0

    if co2 < CO2_YELLOW:
        scaler = make_interpolater(CO2_MIN, CO2_YELLOW, 0, 50)
        scaled_co2 = scaler(co2)
    elif co2 < CO2_RED:
        scaler = make_interpolater(CO2_YELLOW, CO2_RED, 50, 75)
        scaled_co2 = scaler(co2)
    else:
        scaler = make_interpolater(CO2_RED, CO2_MAX, 75, 99)
        scaled_co2 = scaler(co2)
    
    if scaled_co2 > 99:
        scaled_co2 = 99
        
    return scaled_co2

def voc_index(voc):
    #
    # Calculates our 0-99 AQ index for VOC
    #
    scaled_voc = 0

    if voc < VOC_YELLOW:
        scaler = make_interpolater(VOC_MIN, VOC_YELLOW, 0, 50)
        scaled_voc = scaler(voc)
    elif voc < VOC_RED:
        scaler = make_interpolater(VOC_YELLOW, VOC_RED, 50, 75)
        scaled_voc = scaler(voc)
    else:
        scaler = make_interpolater(VOC_RED, VOC_MAX, 75, 99)
        scaled_voc = scaler(voc)
    
    if scaled_voc > 99:
        scaled_voc = 99

    return scaled_voc
       
def make_interpolater(left_min, left_max, right_min, right_max):
    #
    # Scales one range to another...
    # Function that returns a function (closure)
    # see https://stackoverflow.com/questions/1969240/mapping-a-range-of-values-to-another
    #

    # Figure out how 'wide' each range is  
    leftSpan = left_max - left_min  
    rightSpan = right_max - right_min  

    # Compute the scale factor between left and right values 
    scaleFactor = float(rightSpan) / float(leftSpan) 

    # create interpolation function using pre-calculated scaleFactor
    def interp_fn(value):
        return right_min + (value-left_min)*scaleFactor

    return interp_fn
    

def rotate_matrix( m ):
    #
    # Rotate digit matrix by 90 degrees counterclockwise
    # see https://stackoverflow.com/questions/53250821/in-python-how-do-i-rotate-a-matrix-90-degrees-counterclockwise
    #
    return [[m[j][i] for j in range(len(m))] for i in range(len(m[0])-1,-1,-1)]

def display_index(index_value):
    #
    # Display a two digit number on the LEDs
    #
    # Simple way to catch not having a local display, could be done better
    if bar_graph == 0 and matrix_display == 0:
        #print("Nothing to display on...")
        return

    if bar_graph == 1:
        logger.debug("Skipping LED matrix display...")
        bar_index(index_value)
        return
    my_color = 0
    if round(index_value) < green_limit:
        my_color = 2
    elif round(index_value) < yellow_limit:
        my_color = 3
    else:
        my_color = 1
            
    disp_val = str(round(index_value)).rjust(2)

    left_digit = disp_val[:1]
    right_digit = disp_val[-1:]

    display_led(matrix2, right_digit, my_color)
    display_led(matrix1, left_digit, my_color)
    
def display_led(my_matrix, my_value, color):
    #
    # Display a single digit
    #
    # Simple way to catch not having a local display, could be done better
    if bar_graph == 0 and matrix_display == 0:
        #print("Nothing to display on...")
        return

    if my_value == ' ':
        my_digit = display.digits[0]
    else:
        my_digit = display.digits[int(my_value)]

    my_digit = rotate_matrix(my_digit)
    for x in range(8):
        for y in range(8):
            if my_digit[x][y] == 1:
                my_matrix[x,y] = color
            else:
                my_matrix[x,y] = my_matrix.LED_OFF

def display_pollutant(pm10, pm25, co2, voc):
    #
    # Display a two character icon on the LEDs
    #  representing highest-indexed pollutant
    #  Uses icons list 0/1=PM1, 2/3=PM2, 4/5=CO2
    #
    # Simple way to catch not having a local display, could be done better
    if bar_graph == 0 and matrix_display == 0:
        #print("Nothing to display on...")
        return

    index_list = [pm10, pm25, co2, voc]
    max_value = max(index_list)
    max_value_index = index_list.index(max_value)
    icon_index = max_value_index * 2
        
    my_color = 0
    if round(max_value) < green_limit:
        my_color = 2
    elif round(max_value) < yellow_limit:
        my_color = 3
    else:
        my_color = 1
    display_icon(icon_index, my_color)
    
    
def display_icon(icon_index, my_color):
    #
    # Display a two character icon on the display
    # icon_index is the index of the first character
    #
    # Simple way to catch not having a local display, could be done better
    if bar_graph == 0 and matrix_display == 0:
        #print("Nothing to display on...")
        return
    if bar_graph == 1:
        print("Skipping LED matrix icon display...")
        return
    # Loop through digits from 1 to 0
    for digit in range(1, -1, -1):
      if digit == 0:
          my_matrix = matrix1
      else:
          my_matrix = matrix2
      my_digit = display.icons[icon_index + digit]
      my_digit = rotate_matrix(my_digit)
      for x in range(8):
          for y in range(8):
              if my_digit[x][y] == 1:
                  my_matrix[x,y] = my_color
              else:
                  my_matrix[x,y] = my_matrix.LED_OFF

def bar_index(idx):
    #
    # Display an index on the LED bargraph
    # idx = 0 - 99
    # bar color chosen by green_limit, yellow_limit
    #
    my_stick.set_all_LED_brightness(1)
    j = 0
    for i in range(7,-1,-1):
        time.sleep(0.25)
        j = j + 1
        seg_value_start = (j-1) * (100/8)
        seg_value_end = j * (100/8)
        if bar_mode == 2: # All LEDs same color
            if idx <= green_limit:
                my_stick.set_single_LED_color(i, 0, 255, 0)
            elif idx > yellow_limit:
                my_stick.set_single_LED_color(i, 255, 0, 0)
            else:
                my_stick.set_single_LED_color(i, 255, 155, 0)
        else:  # Standard bargraph
            if ((idx > seg_value_start ) and (idx <= seg_value_end)) or (idx > seg_value_end):
                if idx <= green_limit:
                    my_stick.set_single_LED_color(i, 0, 255, 0)
                elif idx > yellow_limit:
                    my_stick.set_single_LED_color(i, 255, 0, 0)
                else:
                    my_stick.set_single_LED_color(i, 255, 155, 0)
            else:
                if bar_mode == 1: # Fill empty segments with white (default)
                    my_stick.set_single_LED_color(i, 25, 25, 25)
                else:  # Turn off empty segments
                    my_stick.set_single_LED_color(i, 0, 0, 0)

    # Turn on first segment if idx <= 12.5 and ZERO_BAR
    if (idx <= (100/8)) and (zero_bar == 1):
        my_stick.set_single_LED_color(7, 0, 255, 0)

def LED_icon(icon_num):

    # Displays rudimentary animation on LED bar graph.

    if icon_num == 1:
        # alt red/grn
        my_stick.set_single_LED_color(7, 255, 0, 0)
        time.sleep(0.2)
        my_stick.set_single_LED_color(6, 0, 255, 0)
        time.sleep(0.2)
        my_stick.set_single_LED_color(5, 255, 0, 0)
        time.sleep(0.2)
        my_stick.set_single_LED_color(4, 0, 255, 0)
        time.sleep(0.2)
        my_stick.set_single_LED_color(3, 255, 0, 0)
        time.sleep(0.2)
        my_stick.set_single_LED_color(2, 0, 255, 0)
        time.sleep(0.2)
        my_stick.set_single_LED_color(1, 255, 0, 0)
        time.sleep(0.2)
        my_stick.set_single_LED_color(0, 0, 255, 0)
        time.sleep(0.2)

    if icon_num == 2:
        # All white
        my_stick.set_single_LED_color(7, 25, 25, 25)
        time.sleep(0.2)
        my_stick.set_single_LED_color(6, 25, 25, 25)
        time.sleep(0.2)
        my_stick.set_single_LED_color(5, 25, 25, 25)
        time.sleep(0.2)
        my_stick.set_single_LED_color(4, 25, 25, 25)
        time.sleep(0.2)
        my_stick.set_single_LED_color(3, 25, 25, 25)
        time.sleep(0.2)
        my_stick.set_single_LED_color(2, 25, 25, 25)
        time.sleep(0.2)
        my_stick.set_single_LED_color(1, 25, 25, 25)
        time.sleep(0.2)
        my_stick.set_single_LED_color(0, 25, 25, 25)
        time.sleep(0.2)
    
############################ START ##############################

# Make sure there's at least one sensor

if max(pm_sensor, scd_sensor, voc_sensor) < 1:
    if bar_graph == 1:
        LED_icon(1)
        time.sleep(5)
    else:
        if matrix_display == 1:
            display_icon(8, 1)
    logger.critical("No sensors found! Exiting...")
    sys.exit()

# startup LED animation
if bar_graph == 1:
    LED_icon(2)
        
if pm_sensor == 1:
    display_icon(0, 2)
    time.sleep(2)
    display_icon(2, 2)
    time.sleep(1)
   
if voc_sensor == 1:
    display_icon(6, 2)
    time.sleep(2)
        
if scd_sensor == 1:
    display_icon(4, 2)
    time.sleep(1)
    scd4x.start_periodic_measurement()
    logger.info("Waiting for scd4x  measurement....")

client = mqtt.Client()
try:
    client.connect("mqtt", 1883, 60)
except Exception as e:
    logger.error("Error connecting to mqtt. ({0})".format(str(e)))
else:
    client.loop_start()
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

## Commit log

2022-03-16 Initial load from experiments
    [back.stl, front.stl, insulate_sense.stl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]
2022-04-11 Added New Connector
2022-06-21 Added STL files plus new service and iaq.py update
    New STL files for sensors. Added the zeroconf service. Minor adds to iaq.py to correct baseline times
    [Port Cover v1.stl, Sensor Cover v5.stl, Sensor Plate v2.stl]
2022-06-22 Fine tune STL files
    [Sensor Cover v10.stl, Sensor Cover v5.stl, Sensor Plate v2.stl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]
